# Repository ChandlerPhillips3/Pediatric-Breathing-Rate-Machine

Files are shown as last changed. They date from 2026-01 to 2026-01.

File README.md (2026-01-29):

# Pediatric Breathing Rate Machine

## Overview

This project was developed by a team of six students for an occupational therapist who works with pediatric patients experiencing anxiety and irregular breathing patterns.

The goal was to design a device that guides children through controlled breathing using **visual LED cues** and **haptic (vibration) feedback** traced along the outline of a hand.

The final design consisted of:
- A laser-cut acrylic hand mounted on a box enclosure
- Addressable NeoPixel LEDs tracing the hand outline
- A vibration motor for haptic feedback
- An Arduino-powered control system
- User-adjustable knobs to control breathing rate, LED colors, and vibration settings

Due to the COVID-19 pandemic (Jan 2020 – May 2020), the project transitioned fully online and a physical prototype was never manufactured. However, a complete digital simulation of the electronics and behavior was developed using CAD tools, TinkerCAD, and Wokwi.

---

## My Role — Embedded Systems Programming (Arduino / C++)

I was responsible for designing and implementing the Arduino code that controls:

- The LED breathing animation mapped to the physical hand layout
- Alternating inhale/exhale timing logic
- Integration of vibration feedback synchronized with the LEDs
- Mapping the physical LED wiring path into a programmable index array for accurate animation
- Timing control for adjustable breathing rates

This required understanding how NeoPixels are addressed by **data chain order** rather than physical placement, and building a custom index mapping (`handPath[]`) to correctly trace the anatomical shape of the hand in software.

---

## How It Works

1. A 3-LED white countdown prepares the patient to begin
2. LEDs move in groups of 5 along the hand:
   - **Green + vibration** → Inhale
   - **Blue** → Exhale
3. The sequence repeats across the entire hand outline
4. The device finishes with a full white illumination of the hand

This creates a guided breathing experience using both visual and haptic biofeedback.

---

## Project Files

| File | Description |
|-----|---|
| `BRM-LED-VIB.ino` | Arduino C++ code controlling LEDs and vibration |
| `Instruction Manual.docx` | Full build, assembly, and usage guide |
| `Final box pieces.DXF` | CAD files for laser-cut enclosure |
| `hand dxf.DXF` | CAD file for acrylic hand layout |
| `Final Arduino.PNG` | Wiring layout reference |

**Required Library:** Adafruit NeoPixel

---

## Live Simulation

Wokwi Demo:  
https://wokwi.com/projects/453890159644208129

This simulation demonstrates the complete LED breathing sequence and vibration logic.

---

## Technical Resources Used

- Adafruit NeoPixel Library📚
  https://learn.adafruit.com/adafruit-neopixel-uberguide/arduino-library-use

- Wokwi Arduino Simulator
- TinkerCAD Circuits
- AutoCAD / DXF for enclosure design

---

## Future Improvements

- [ ] Physical prototype build
- [ ] Adjustable dial for breathing rate
- [ ] Adjustable color selection
- [ ] Switch to enable/disable vibration feedback

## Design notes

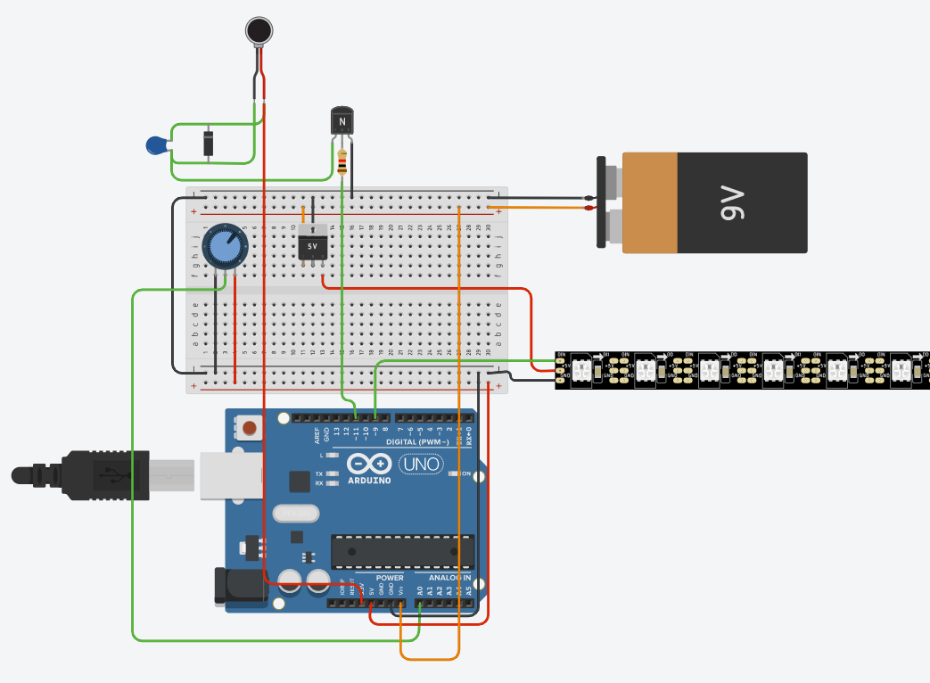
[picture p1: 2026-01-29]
Final Arduino.PNG

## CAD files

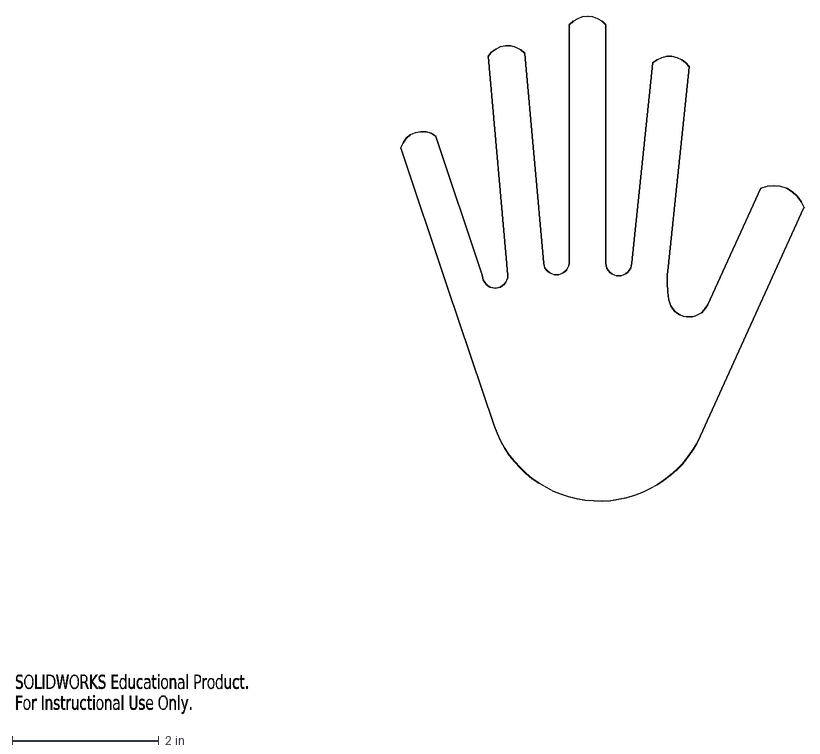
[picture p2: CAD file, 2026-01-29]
hand dxf.DXF
SOLIDWORKS Educational Product.
For Instructional Use Only.

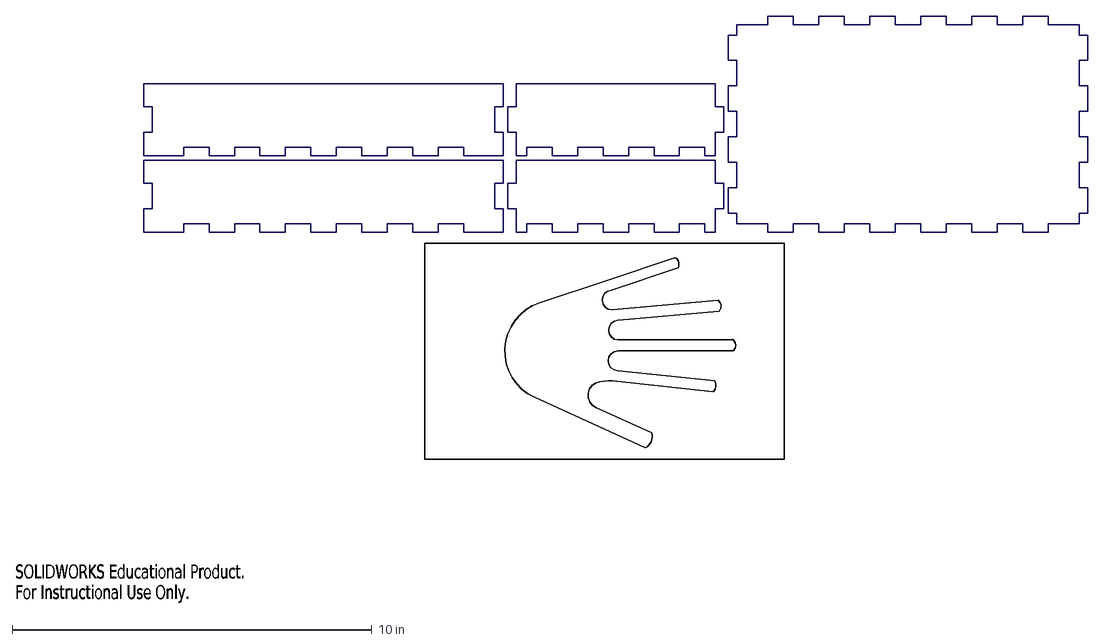
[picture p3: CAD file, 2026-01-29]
Final box pieces .DXF
SOLIDWORKS Educational Product.
For Instructional Use Only.

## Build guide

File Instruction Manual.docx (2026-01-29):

# Introduction

## What is this for?

Children can get easily worked up while doing certain activities and can also become anxious or nervous in certain settings, this product helps the child lower their breathing rate and regain their focus. This manual will show you how to build a device to help lower a child's breathing rate, by using a common technique of tracing the outside of the hand and breathing in and out.

## This is for you if…

This was designed for anyone regularly working with young children one-on-one or in small groups. The product is compatible with children roughly ages 4 to 9 years old.

## This product should stop being used if…

If the child or user has issues with flashing lights or vibration, the product should either be used with just the vibration and without the motor or vice versa. This product is meant to calm the user down, so if it increases anxiety, then stop using it.

# Materials

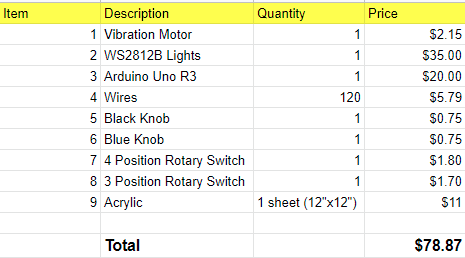
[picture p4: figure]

## Acrylic Sheets

You can get sheets of the right material cut to the right size at your local plastic stores. Colorado Plastics was a great resource for us.

## Arduino Circuitry

All the Arduino circuitry can be purchased through Amazon or various electronic companies such as Sparkfun or All Electronics. The main and necessary components for the setup of the Arduino, are an Arduino, LED strips, haptic motors, and rotary switches.

Arduino Uno R3 (Amazon)

Flexible LED Strip Light (Amazon)

Breadboard Jumper Wires (Amazon)

Haptic Motor (Sparkfun)

3 and 4 Position Rotary Switches (All Electronics)

# Manufacturing the Parts

## 1. Box

We’ll be using a laser cutter to manufacture the acrylic pieces to fit together into a box shape. We’ve attached the .dxf files to be able to cut the pieces. The settings depend on the specific machine you are using, but you want to hairline (cut through) the edges, and this would be possible with acrylic.

## 2. Hand

We’ll be using a laser cutter to manufacture the acrylic piece for the hand. We’ve attached the .dxf files to be able to cut the piece. The settings depend on the specific machine you are using, but you want to hairline (cut through) the edge, and raster (engrave) the indentations of the LEDs to sit in, and this would be possible with acrylic.

## 3. LED Strip and Haptic Motor Programming

The provided code functions so that the LED strip and haptic motor run for a set amount of time as determined by the three position rotary switch. This would be either two, three, or four second intervals based on the patient’s size and corresponding target breathing rate. For example, if the switch is turned to the two second setting, the lights will trace up one side of the thumb and the haptic motor will vibrate for two seconds. Then, the entire apparatus will pause for a brief amount of time before repeating this process for the other side of the thumb, then for the remaining fingers. The lights are programmed such that no matter the length of the finger, it will take the predetermined amount of time to trace one side of that finger. This means that the LEDs will light up more quickly for the longer fingers with more LEDs to maintain a constant time to trace out each finger. This circuit is powered by a 9 Volt battery, and has a variety of other components such as a regulator, transistor, resistor, capacitor, and diode to regulate the flow of current and ensure that everything runs smoothly. Ideally, there would be another four position rotary switch which gives the user the option of having both the lights and motor run, only one of the two, or neither. This would be fairly easy to set up, repeating portions of the same provided code three times within a case structure for the switch, with another option for having everything off. For example, if the user turned the switch to the lights only setting, there would be an “if statement” with the provided block of code minus the lines to turn the haptic motor on and off. Although we had planned to include this component in our Tinkercad design, it was already running very slowly due to the Neopixel strips and haptic motor, so we decided to leave instructions for this second switch instead of integrating it into our circuit.

# Assembling the Parts

## 1. The Circuit

To create the circuit, obtain all the required materials and find the schematics for wiring the Arduino. The schematics are located in the file with the .dxt files for the box. Carefully, wire the haptic motor, LED light strip, the switches, and the battery into the breadboard and Arduino. To get the circuit fully functioning, download the code onto the Arduino. To do this, plug the USB cable into the Arduino and get the code from the folder of files. Go to Choose Tools→Board→Arduino and find your board in the Arduino menu. Then, choose the correct serial port for your board and click the Upload button. Test the Arduino to make sure that the program has been loaded by testing the knobs. Then, the circuit should be complete for use.

## 2. The Box

To secure the different pieces of the box, the best way is to use acrylic cement. By injecting acrylic cement into the edges of the box, a clean bond can be made and the pieces will hold together. To do this, fill a syringe with acrylic cement. Then, holding the edges of the plastic together slowly release the acrylic cement from the syringe while moving along the whole edge. Finally, hold the pieces in the same position for approximately 5 minutes to let the cement solidify and bond. Repeat until all the edges have been bonded together. Let the box dry for 24 to 48 hours before adding the remaining components, to make sure that the box is sturdy for use.

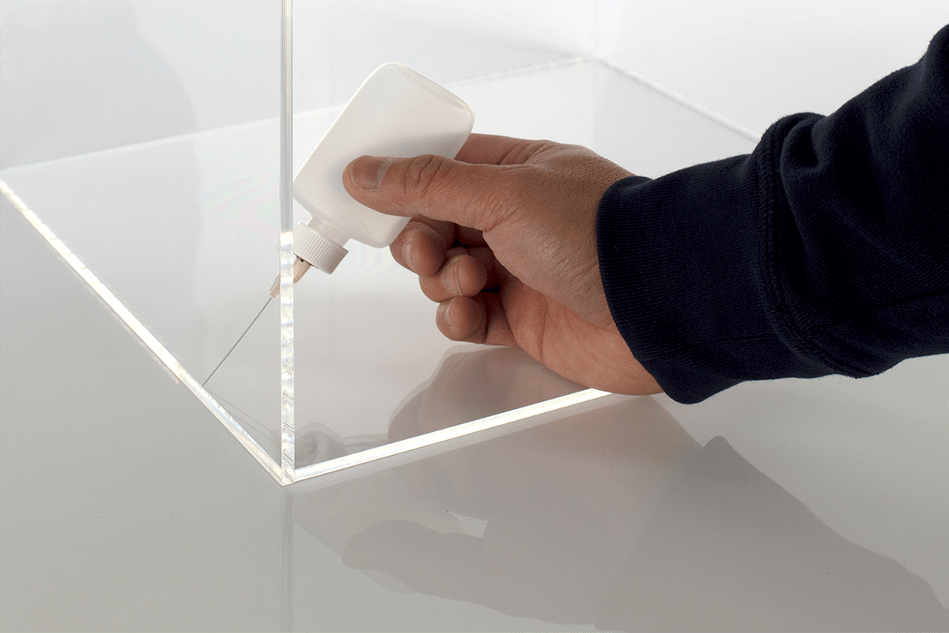
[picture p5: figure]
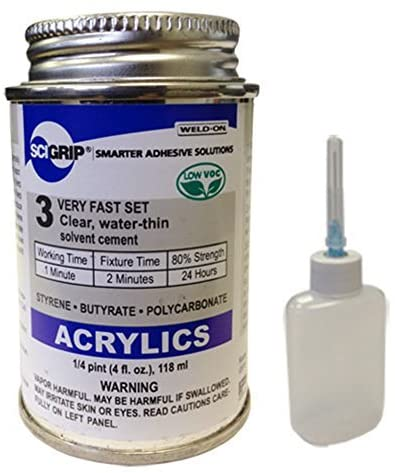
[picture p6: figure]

The image on the left shows how to hold the pieces and create a clean bond.

The image to the right is a common type of acrylic cement

The images below show how the pieces of the box go together.

## 3. LED Strips

Although in the Tinkercad model the LED strips are simply aligned in a rectangle, when assembling the box there is a divot in the hand into which the LEDs can be threaded to follow that shape. The clear acrylic of the hand portion will allow the light from the LEDs to shine through so that the child can trace the pattern of the colorful lights with his or her finger in time with the target breathing rate set by the machine. These LED strips will be wired to the Arduino Uno inside the box as demonstrated in the digital models provided.

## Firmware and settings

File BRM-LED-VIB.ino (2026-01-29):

#include <Adafruit_NeoPixel.h>

#define PIN 6
#define NUM_LEDS 57
#define VIBE_PIN 9

Adafruit_NeoPixel strip(NUM_LEDS, PIN, NEO_GRB + NEO_KHZ800);

// Correct NeoPixel indexes for your hand path (DO NOT USE RGB#, INDEX OF WIRING FROM ARDUINO)
int handPath[] = {
  0,1,2,//Countdown to start (Zero Index)
  3,4,5,6,7, //Inhale
  8,9,10,11,12,//Exhale
  13,14,15,16,17,//I
  18,19,20,21,22,//E
  23,24,25,26,27,//I
  28,29,30,31,32,//E
  33,34,35,36,37,//I
  38,39,40,41,42,//E
  43,44,45,46,47,//I
  48,49,50,51,52,//E
  53,54,55,56//FINISH
};

int delayTime = 300;//time each LED takes

void setup() {
  strip.begin();
  strip.show();
  pinMode(VIBE_PIN, OUTPUT);
}

void loop() {

  // Countdown (first 3 LEDs)
  for (int i = 0; i < 3; i++) {
    strip.setPixelColor(handPath[i], strip.Color(255,255,255));
    strip.show();
    delay(400);
  }

  delay(1000);
  strip.clear();

  bool inhale = true;

  // Breathing animation
  for (int i = 3; i < 50; i= i + 5) {
    for (int j = 0; j < 5; j++) {
      strip.clear();

      if (inhale) {
        strip.setPixelColor(handPath[i + j], strip.Color(0,255,0)); // green = inhale
        digitalWrite(VIBE_PIN, HIGH);
      } else {
        strip.setPixelColor(handPath[i + j], strip.Color(0,0,255)); // blue = exhale
        digitalWrite(VIBE_PIN, LOW);
      }
      strip.show();
      delay(delayTime);
    }

    inhale = !inhale;
  }

  // Finish: light up entire hand white
  //pauses for a couple seconds to decide to turn off or run again
  strip.clear();
  setHandColor(255, 255, 255);
  strip.show();
  delay(2000);
  strip.clear();
  setHandColor(0, 0, 0);
  strip.show();
  delay(4000);
}

// Function to set the whole hand to a color
void setHandColor(int r, int g, int b) {
  for (int i = 0; i < NUM_LEDS; i++) {
    strip.setPixelColor(handPath[i], strip.Color(r, g, b));
  }
}
